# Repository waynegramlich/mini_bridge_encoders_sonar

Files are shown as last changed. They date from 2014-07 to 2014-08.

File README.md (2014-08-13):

# mini_bridge_encoders_sonar

The Bridge/Encoders/Sonar Mini-Shield is a
[Busino](https://github.com/waynegramlich/busino)
compatible mini-shield.  It provides the ability
to connectxyzo to:

* 2 small 1A DC motors,

* 2 shaft encoders, and

* 2 Sonar range finders.

The power comes from the motor power bus and is
fully electrically isolated (using opto-isolators)
from the logic bus.

Currently, everything is located in the `rev_a` directory.

## Revision A

The revision A schematic is available as either
`mini_bridge_encoders_sonar.pdf` or as
`mini_bridge_encoders_sonar.svg`.

The is circuit is broken to electrically isolated sections.
The schematic shows the electrical isolation boundary.

### Logic Side

Logic ground comes in on N2 (pins 5 and 6).  5 Volts
comes in on N2 (pin 3.)  5 volts and ground are routed
to the two shaft encoder connectors N3 and N4 as well
as the two sonar connectors N7 and N8.

The first shaft encoder connects the A and B quadrature
signals to  D5 and D6 on N1.  The second shaft encoder
connects the A and B  quadrature signals to D4 and D2.

{more goes here.}

### Programming

<Table Border="1">
  <TR>
    <TH>Arduino Pin</TH>
    <TH>Function</TH>
  </TR>
  <TR>
    <TD>D0</TD>
    <TD>No Connection</TD>
  </TR>
  <TR>
    <TD>D1</TD>
    <TD>No Connection</TD>
  </TR>
  <TR>
    <TD>D2</TD>
    <TD>Encoder N4-2 Phase A</TD>
  </TR>
  <TR>
    <TD>D3</TD>
    <TD>Sonar N8-3 Trigger</TD>
  </TR>
  <TR>
    <TD>D4</TD>
    <TD>Encoder N4-3 Phase B</TD>
  </TR>
  <TR>
    <TD>D5</TD>
    <TD>Encoder N3-2 Phase A</TD>
  </TR>
  <TR>
    <TD>D6</TD>
    <TD>Encoder N3-3 Phase B</TD>
  </TR>
  <TR>
    <TD>D7</TD>
    <TD>H-Bridge 4A</TD>
  </TR>
  <TR>
    <TD>D8</TD>
    <TD>H-Bridge 3A</TD>
  </TR>
  <TR>
    <TD>D9</TD>
    <TD>Sonar N7-3 Trigger</TD>
  </TR>
  <TR>
    <TD>D10</TD>
    <TD>H-Bridge 3/4 Enable</TD>
  </TR>
  <TR>
    <TD>D11</TD>
    <TD>H-Bridge 1/2 Enable</TD>
  </TR>
  <TR>
    <TD>D12</TD>
    <TD>H-Bridge 2A</TD>
  </TR>
  <TR>
    <TD>D13</TD>
    <TD>H-Bridge 1A</TD>
  </TR>
  <TR>
    <TD>A0</TD>
    <TD>Sonar N8-2 Echo Return</TD>
  </TR>
  <TR>
    <TD>A1</TD>
    <TD>Sonar N7-2 Echo Return</TD>
  </TR>
  <TR>
    <TD>A2</TD>
    <TD>No Connection</TD>
  </TR>
  <TR>
    <TD>A3</TD>
    <TD>No Connection</TD>
  </TR>
  <TR>
    <TD>A4</TD>
    <TD>No Connection</TD>
  </TR>
  <TR>
    <TD>A5</TD>
    <TD>No Connection</TD>
  </TR>
</Table>

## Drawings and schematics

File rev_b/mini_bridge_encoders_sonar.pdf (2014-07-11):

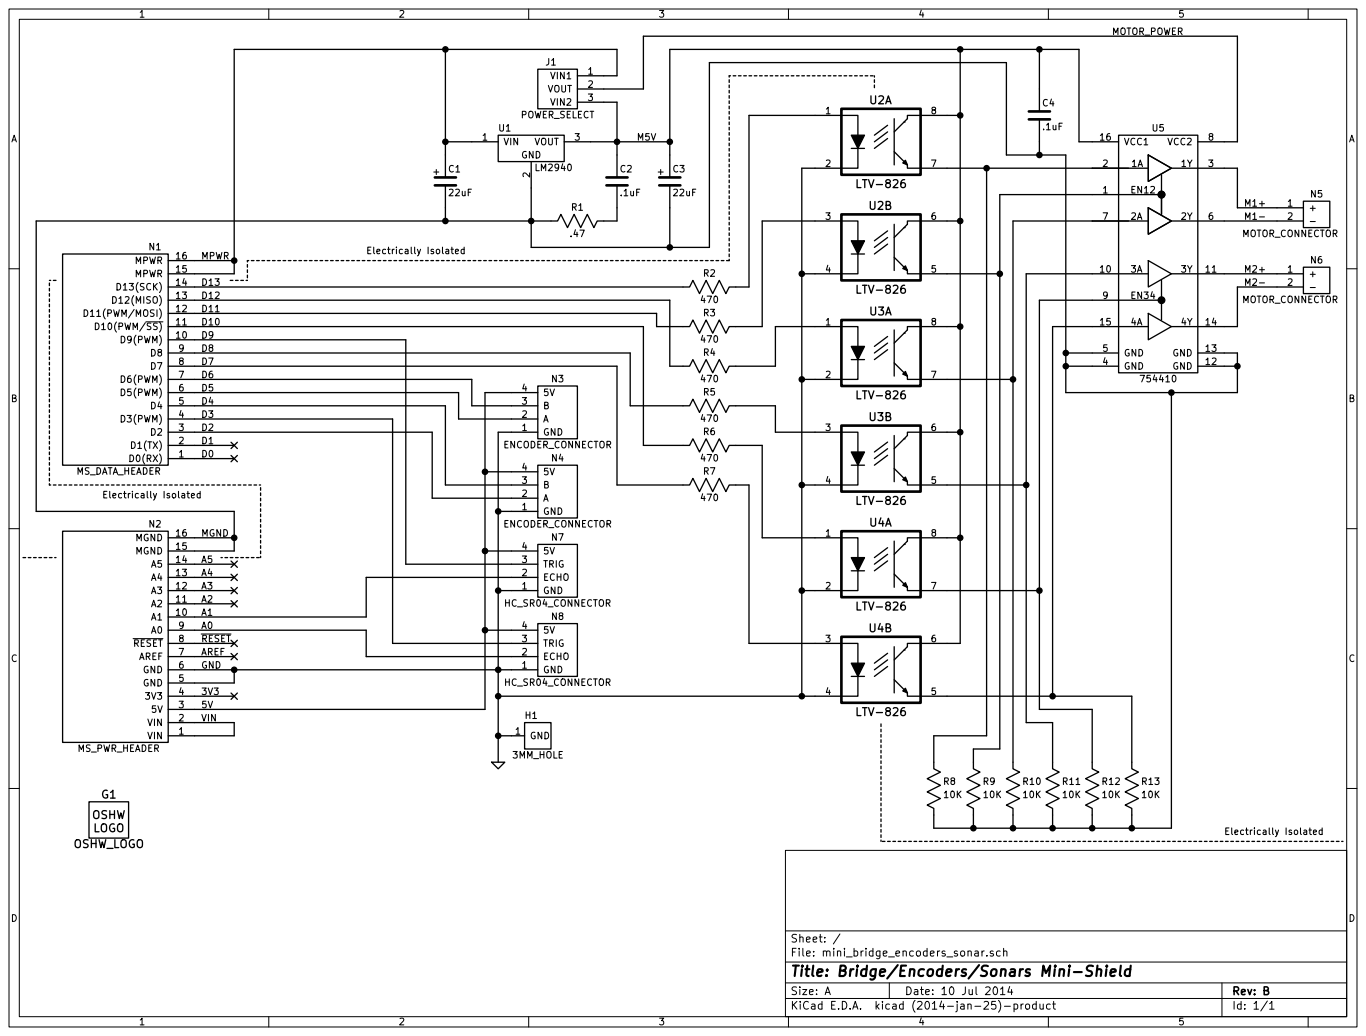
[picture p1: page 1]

File: mini_bridge_encoders_sonar.sch Sheet: /
Id: 1/1 Title: Bridge/Encoders/Sonars Mini-Shield

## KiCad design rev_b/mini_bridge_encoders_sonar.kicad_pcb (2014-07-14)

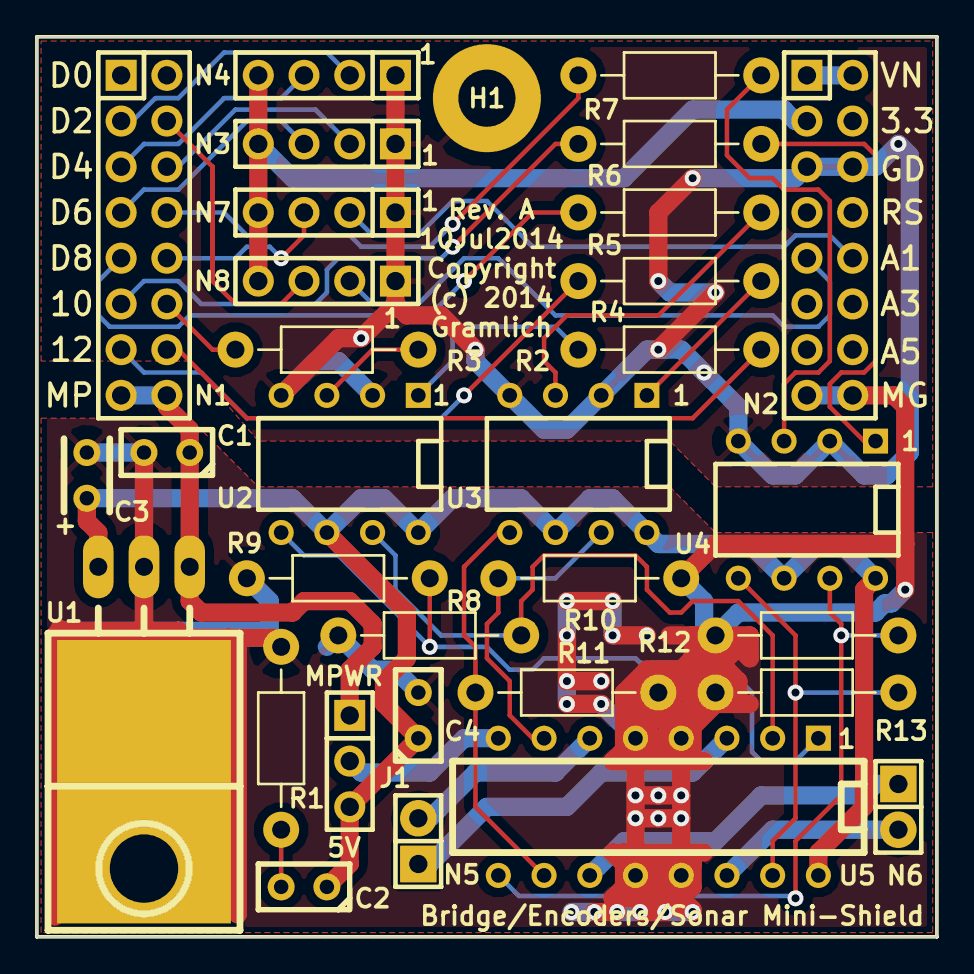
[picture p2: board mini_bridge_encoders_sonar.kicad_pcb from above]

Board: 2 copper layers, 50.0 x 50.0 mm, 33 parts (1 on the bottom side), 38 nets.

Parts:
C1: 22uF; Capacitor3MMDiscRM2.5
C2, C4: .1uF; Capacitor3MMDiscRM2.5
C3: 22uF; Capacitor4x3RM2-5_RevB
G1: OSHW_LOGO; OSHW_LOGO_400mil
H1: 3MM_HOLE; MountingHole_3mm
J1: POWER_SELECT; Pin_Header_Straight_1x03
N1: MS_DATA_HEADER; Pin_Header_Straight_2x08
N2: MS_PWR_HEADER; Pin_Header_Straight_2x08
N3, N4: ENCODER_CONNECTOR; Pin_Header_Straight_1x04
N5, N6: MOTOR_CONNECTOR; Pin_Header_Straight_1x02
N7, N8: HC_SR04_CONNECTOR; Pin_Header_Straight_1x04
R1: .47; Resistor_Horizontal_400
R2, R3, R4, R5, R6, R7: 470; Resistor_Horizontal_400
R8, R9, R10, R11, R12, R13: 10K; Resistor_Horizontal_400
U1: LM2940; TO-220_Neutral123_Horizontal_LargePads
U2, U3, U4: LTV-826; DIP-8__300
U5: 754410; DIP-16__300

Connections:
/5V: N2.3, N3.4, N4.4, N7.4, N8.4
/A0: N2.9, N8.2
/A1: N2.10, N7.2
/D2: N1.3, N4.2
/D3: N1.4, N8.3
/D4: N1.5, N4.3
/D5: N1.6, N3.2
/D6: N1.7, N3.3
/D7: N1.8, R7.1
/D8: N1.9, R5.1
/D9: N1.10, N7.3
/D10: N1.11, R6.1
/D11: N1.12, R3.1
/D12: N1.13, R4.1
/D13: N1.14, R2.1
/M1+: N5.1, U5.3
/M1-: N5.2, U5.6
/M2+: N6.1, U5.11
/M2-: N6.2, U5.14
/M5V: C2.1, C3.1, C4.1, J1.3, U1.3, U2.6, U2.8, U3.6, U3.8, U4.6, U4.8, U5.16
/MGND: C1.2, C3.2, C4.2, N2.15, N2.16, R1.1, R8.1, R9.1, R10.1, R11.1, R12.1, R13.1, U1.2, U5.4, U5.5, U5.12, U5.13
/MOTOR_POWER: J1.2, U5.8
/MPWR: C1.1, J1.1, N1.15, N1.16, U1.1
/VIN: N2.1, N2.2
GND: H1.1, N2.5, N2.6, N3.1, N4.1, N7.1, N8.1, U2.2, U2.4, U3.2, U3.4, U4.2, U4.4
unnamed: C2.2, R1.2
unnamed: R2.2, U2.1
unnamed: R3.2, U2.3
unnamed: R4.2, U3.1
unnamed: R5.2, U3.3
unnamed: R6.2, U4.1
unnamed: R7.2, U4.3
unnamed: R8.2, U2.7, U5.2
unnamed: R9.2, U2.5, U5.1
unnamed: R10.2, U3.7, U5.7
unnamed: R11.2, U3.5, U5.10
unnamed: R12.2, U4.7, U5.9
unnamed: R13.2, U4.5, U5.15

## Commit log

2014-06-25 Made of copy of mini_template.
    [mini_bridge_encoders_sonar.kicad_pcb, mini_bridge_encoders_sonar.sch]
2014-06-30 Initial schematic complete.
    [mini_bridge_encoders_sonar.sch]
2014-07-03 Initial layout is complete.
    [mini_bridge_encoders_sonar-B_Cu.gbl, mini_bridge_encoders_sonar-B_Mask.gbs, mini_bridge_encoders_sonar-B_SilkS.gbo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]
2014-07-10 Got Revision A in pretty good shape.
    [mini_bridge_encoders_sonar-B_Cu.gbl, mini_bridge_encoders_sonar-B_Mask.gbs, mini_bridge_encoders_sonar-B_SilkS.gbo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]
2014-07-11 Layed out board again (Rev. B) with separate GND and MGND zones. The electrical isolation is also physical isolation.
    [mini_bridge_encoders_sonar.kicad_pcb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]
2014-07-13 Added Edge Cuts.
    [mini_bridge_encoders_sonar-B_Cu.gbl, mini_bridge_encoders_sonar-B_Mask.gbs, mini_bridge_encoders_sonar-B_SilkS.gbo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]
2014-07-14 Dealt with some more PCB edge incursions.
    [mini_bridge_encoders_sonar-B_Cu.gbl, mini_bridge_encoders_sonar-B_Mask.gbs, mini_bridge_encoders_sonar-B_SilkS.gbo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]

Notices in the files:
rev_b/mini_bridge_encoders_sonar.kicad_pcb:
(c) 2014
